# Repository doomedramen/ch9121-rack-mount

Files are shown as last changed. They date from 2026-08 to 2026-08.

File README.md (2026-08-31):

# CH9121 UART-to-Ethernet Rack Panel Carrier

> **Also in this repo:** [`pi5_ch9121_1u.scad`](pi5_ch9121_1u.scad) — a 1U
> 10-inch rack panel that holds one Raspberry Pi 5 and this carrier. See
> [the panel section](#1u-panel-raspberry-pi-5--carrier) at the bottom.

A rear-mounted 3D-printable **open tray** that holds a CH9121 UART-to-Ethernet
module behind a hand-cut opening in a Raspberry Pi rack fascia. The board's
2×8 pin header stays fully exposed so it can be wired to the Pi's GPIO with
dupont jumpers.

| File | Purpose |
|---|---|
| `ch9121_mount.scad` | Parametric OpenSCAD source. Every dimension is a named variable at the top. |
| `ch9121_carrier.stl` | Printable export. Manifold, genus 5 (RJ45 opening, 2 flange bores, 2 board bores). |
| `ch9121_coupon.stl` | **Print this first.** The front 14 mm of the part only — a few minutes on the bed. Checks that the board's screw holes and the magjack line up, and lets you test-press an insert before committing. |
| `ch9121_fascia_stencil.stl` | 2 mm flat plate for marking the fascia: flange outline, the 17.6 × 15.3 opening, and the two M2 holes. Hold it on the panel, mark or drill through, cut the opening to the line. Symmetric both ways so it can't go on backwards. |
| `renders/` | `iso.png` (into the tray), `fit.png` (module shown as reference geometry), `flange.png` (front elevation), `underside.png` (insert bores), `stencil.png`. |
| `render.sh` | Regenerates every STL and every PNG in `renders/` from the two sources. Run it after editing either. |

## Design

Open on top, screwed at both ends — no lid, no rails, no snap tab, no glue.

```
        flange (Z 0-4)          open tray (Z 4-48.2)
        +--------+
  RJ45  |  []    |======================\        <- side walls stop 7mm short
  hole  |        |   ribs carry the PCB  |          of the rear so nothing
        +--------+======================/          crowds the dupont housings
         ^      ^
         M2 inserts, screws enter from the front of the panel
```

- **X** = left / right
- **Y** = up / down — **Y = 0 is the top face of the tray floor**
- **Z** = front → back — Z = 0 is the outside face of the flange

Front to back: a 4 mm flange/front-stop slab with the RJ45 cutout and the two
M2 insert bosses, then a U-channel — floor plus two side walls — running back
48.2 mm. Two continuous ribs at the PCB's mounting-hole X positions run the
whole length of the tray and carry the M2 inserts the board screws down to.

Overall: **36 × 30 × 48.2 mm**.

### Two sets of brass heat-set inserts

**M2 throughout** — one insert size, one screw, one driver.

| Where | Bore | Depth | Screw enters from |
|---|---|---|---|
| Flange, 2 off at X ±14 | `flange_insert_d` 3.2 | 4.0 mm | the **front** of the rack panel |
| Tray ribs, 2 off at X ±10.16 | `pcb_insert_d` 3.2 | 4.0 mm | **above**, through the board's own holes (insert itself presses in from the tray *underside* — see below) |

The flange bores open at the front face and are backed by 2.5 mm bosses on the
rear face, giving 6.5 mm of stack for a 4 mm insert without thickening the
whole flange. Those bosses sit at Y 7.7–14.2, clear above the tray, so they
never foul the board.

The PCB bores open **downward, at the underside of the tray floor**, and the
insert is pressed in from there. It cannot go in from above: the bore mouth
sits 2.54 mm behind a flange that stands ~23 mm proud of the tray floor, and a
soldering iron's barrel fouls the flange long before the tip seats. The
underside is a flat open face with the flange protruding only 0.55 mm past it.
The screw then passes down through the board and a 2.4 mm clearance section to
reach the insert below — M2×6 gives 2.9 mm of engagement in the 4 mm insert
and still clears the tray bottom by 1.1 mm.

Those bores are cut in `pcb_screw_holes()` at **assembly level**, not inside
`pcb_rails()`. The tray floor is a separate solid, so subtracting them from the
ribs alone leaves the floor plugging the bottom of every bore — which is
exactly what happened, and is why the exported genus is worth checking (5:
RJ45 opening, two flange bores, two board through-holes).

Where the board is allowed to touch is driven by what hangs below it. The
magjack's heat-staked pegs and their solder joints span up to ~15.3 mm, so the
seating ribs start at X ±9.6, leaving a 19.2 mm clear channel — 1.95 mm of
margin each side. Only a short pad at each screw position (Z 4–9.3, forward
of the pegs) reaches inboard to ±7.8 to give the M2 bore a 0.76 mm collar.
Under the header the ribs are cut away to the floor entirely, so it makes no
difference exactly where the header pads sit; the board is supported for its
first 32 mm and cantilevers the last 11 mm, which 1 mm FR4 handles fine.

## The module

Measured off the board with calipers. It is an imperial design — 1″ wide,
0.1″ hole inset, 0.1″ header pitch:

| | |
|---|---|
| PCB | **25.4 × 43.18 × 1.0 mm** (1″ × 1.7″) — the 23 mm width repeated across listings is wrong |
| RJ45 magjack (HanRun HR911105A) | 12.7 mm (0.5″) tall above the board, overhangs the front edge by 5.08 mm (0.2″) |
| Mounting holes | Two, at the front corners, **2.54 mm (0.1″) diameter**, centres 2.54 mm (0.1″) in from every edge → X ±10.16, 2.54 back from the front |
| Under the board | 3 mm of solder tail to clear |
| 2×8 header | rear edge, 0.1″ pitch, pins stand 7.62 mm (0.3″) proud |

The board is pushed forward until its front edge butts the back face of the
flange slab at Z = 4.0 — that is its only hard stop, so it is where the board
actually sits. The magjack overhangs 5.08 mm against a 4.0 mm slab, so the
connector face ends up **1.08 mm proud** of the flange and noses into the
fascia cut-out. Screw positions are measured from that seated position, so
`pcb_front_z` must equal `front_t`; there is an assert on it.

## Print the coupon first

```bash
/Applications/OpenSCAD.app/Contents/MacOS/OpenSCAD --backend=manifold -o ch9121_coupon.stl -D 'part="coupon"' ch9121_mount.scad
```

It's the front 14 mm of the part — flange, both insert bosses, both flange
screw holes, the RJ45 opening. Sit the board against it and check the two
screw holes line up and the magjack drops into the opening. That's the whole
risk, and it costs a few minutes of filament instead of a two-hour print.

The RJ45 opening started deliberately loose and has been closed up over two
coupon prints. It now sits at **16.8 × 14.5** — 0.4 mm per side on width
(`rj45_clear_x`), 0.9 mm per side on height (`rj45_clear_y`) — and the whole
opening is lifted 1 mm by `rj45_y_trim`, because the connector sits that much
higher than `pcb_top_y + rj45_body_h/2` predicts.

If you ever change `rj45_body_h`, `standoff_h` or `pcb_t`, open both clearances
back out to ~1.5 and re-print the coupon before committing to a full part.

## Still to confirm

| Variable | Default | What to check |
|---|---|---|
| `pcb_insert_d` / `flange_insert_d` | 3.2 | Both are M2. 3.2 suits the common M2×4.0 insert with a 3.2 mm OD, but some M2 inserts want 3.5 — check yours before pressing. |
| `rib_inner_x` | 9.6 | Must clear the magjack's underside pegs (photos put them around ±6.5) and the header pins at ±8.89. |

Everything else is measured. If a number turns out wrong, it's one variable at
the top of the `.scad` — change it, re-run, and the asserts will tell you if
the change broke something else.

Three of those asserts currently pass by less than a print's worth of error,
so a clean render is weaker evidence than it looks — check them with calipers
on the coupon rather than trusting the model:

| Assert | Required | Actual | Slack |
|---|---|---|---|
| seating band wide enough to hold the board flat | 3.0 | 3.1 | 0.1 |
| ribs clear of the header pins | 9.39 | 9.6 | 0.21 |
| standoffs clear the RJ45's underside posts | 0.5 | 0.6 | 0.1 |

They are this tight because `rib_inner_x` is squeezed from both sides — the
header pins push it outboard, the seating band pulls it inboard — and it is
the one dimension in the table above that is still unverified. Confirm the
magjack and header spans on a real board before widening either bound.

## Printing

- PETG preferred; PLA or ABS/ASA fine.
- **Flange face down on the bed** (the default orientation in the file).
- **No supports needed.** Nothing in the model overhangs in −Z: the tray, the
  ribs and the gussets are all rooted in the flange slab at Z = 4 and grow
  straight up, and the bosses are rectangular rather than round for exactly
  that reason. The only overhangs are the tops of the two M2 bores, which are
  3.2 mm horizontal holes — they bridge fine, and a heat-set insert melts
  through any droop anyway.
- Walls 2.0 mm, floor 2.5 mm, flange 4.0 mm.

## Rebuilding

```bash
/Applications/OpenSCAD.app/Contents/MacOS/OpenSCAD --backend=manifold -o ch9121_carrier.stl ch9121_mount.scad
```

`part` selects what gets exported — `"carrier"` (default), `"coupon"` or
`"stencil"`:

```bash
OS=/Applications/OpenSCAD.app/Contents/MacOS/OpenSCAD
$OS --backend=manifold -o ch9121_carrier.stl        ch9121_mount.scad
$OS --backend=manifold -o ch9121_coupon.stl         -D 'part="coupon"'  ch9121_mount.scad
$OS --backend=manifold -o ch9121_fascia_stencil.stl -D 'part="stencil"' ch9121_mount.scad
```

`show_reference = true` adds translucent PCB / magjack / header stand-ins for a
visual fit check. Leave it `false` when exporting.

`./render.sh` regenerates every STL and every PNG in `renders/` in one go,
with the camera angles and colour schemes the committed images use. Run it
after any change to either source so the checked-in artefacts don't drift
from the code.

## Hardware

| | |
|---|---|
| Inserts | 4 × M2 heat-set, **4.0 mm long, 3.2 mm OD**. One size covers both bores. |
| Screws | 4 × **M2×6 button head**. Length is measured under the head, so it is 6 mm of penetration at both ends. |

Button head rather than countersunk on the board: the PCB's holes are
plain-drilled, so a conical head cannot seat — it bears on a 1.27 mm rim of
FR4 and wedges. Countersunk would be fine on the flange (flush panel) but then
you would have to countersink the fascia by hand, and button head costs only
~1.1 mm of head standing proud.

**Do not use M2×8 on the board** — 7 mm of penetration against 6.1 mm of
material punches through the tray floor. M2×8 is fine on the flange if your
fascia is thicker than ~3 mm; the relief bore runs right through, so the tip
just enters open air behind.

## Assembly order

1. Print `ch9121_coupon.stl`. Check the screw holes line up, the magjack drops
   into the opening, and an insert presses in cleanly.
2. Print `ch9121_carrier.stl` and `ch9121_fascia_stencil.stl`.
3. **Dry-fit the board before pressing any inserts.** They do not come out.
4. Press the two board inserts in from the **tray underside**, and the two
   flange inserts in from the **front face**. Seat each a hair below flush —
   proud stops the part sitting flat, and on the flange it holds the carrier
   off the panel. Scrape back any ridge of displaced plastic.
5. Hold the stencil on the fascia, mark through it, cut. That is a
   17.6 × 15.3 mm opening (`rack_hole_w` / `rack_hole_h`, the printed opening
   plus 0.4 mm per side) plus two M2 clearance holes at 28 mm spacing. It
   clears the 1.08 mm of magjack standing proud of the flange with 0.8 mm to
   spare all round.
6. Screw the carrier to the fascia, then the board into the tray.

---

## 1U panel: Raspberry Pi 5 + carrier

`pi5_ch9121_1u.scad` is a 254 × 44.0 mm 10-inch-rack 1U panel adapted from the
reference mounts in `pi_references/`. **The carrier is part of the print**: the
panel `include`s `ch9121_mount.scad` and unions `ch9121_carrier()` onto the
back of the fascia, flange face flush with the panel front. The carrier's two
flange screws and bosses are dropped (`include_flange_screws = false`) — there
is nothing to screw to when the flange grows out of the panel — and the fascia
carries the carrier's own test-fitted 16.8 × 14.5 opening rather than the
looser hand-cut stencil hole. All carrier dimensions stay in
`ch9121_mount.scad`; there is one source of truth.

| File | Purpose |
|---|---|
| `pi5_ch9121_1u.scad` | Parametric source. Pi 5 dimensions verified against the official mechanical drawing. |
| `pi5_ch9121_1u.stl` | The panel. Manifold, genus 8 (4 ear slots, Pi port opening, RJ45 tunnel, 2 carrier board bores). |
| `pi5_ch9121_1u_coupon.stl` | Front 14 mm slice — checks the Pi port opening and the CH9121 board alignment before a full print. |
| `renders/panel_*.png` | `iso`, `fit` (Pi / cooler / adapter / CH9121 ghosts), `front`. |

*A subtlety for anyone editing the source: the model is authored in a
mirrored frame (+X = the front viewer's **left**) and the final assembly
emits `mirror([1,0,0])` of everything — that mirror is what puts the Pi's
power/HDMI edge on the open-bay side. A Pi with ports facing front and
cooler up has its power edge on the viewer's left; there is no way to flip
it without pointing the ports backwards or the cooler down.*

**Layout, viewed from the front, left → right:**

1. **Open cable bay** (~110 mm) — the Pi's USB-C power and micro-HDMI → HDMI
   adapter exit sideways into this space. The adapter plus a mated full-size
   HDMI plug needs ~75 mm; there is ~110.
2. **Pi 5 bay** — board flat, Active Cooler up, USB/Ethernet through the
   fascia (flush: the ports overhang 3.0 mm against a 3 mm fascia, per the
   official drawing), SD card reachable from the rear. The board sits on two
   full-length rails rooted in the fascia, on four **M2.5** heat-set inserts
   (bore 3.5, pressed in from above), screwed with **M2.5×6** through the
   Pi's corner holes. The Active Cooler uses its own two dedicated holes, so
   the corners stay free. Those cooler holes sit 6 mm inboard of the rail
   lines at exactly the insert positions (official drawing: 6 mm from the
   GPIO-corner and USB-C-corner mounting holes), and the cooler's spring
   pins clip **through** the board and flare ~2.5 mm below it — which caps
   how far a rail may reach inboard at 2.75 mm (0.25 mm to spare at a 6 mm
   flare). The rails are **centred** on their hole lines at that reach, 5.5 mm
   wide, so each insert bore sits mid-rail with a 1.0 mm wall all round and
   the iron goes in straight. Asserts guard the clip clearance, the
   insert-bore wall, and the rails being centred.

   Each bore mouth is sunk by a 4.0 × 0.3 mm relief counterbore. These
   inserts press from *above* — unlike the carrier's, there is no reaching
   them from below — which puts the insert's own top face right at the
   board's seating plane, so one left standing proud would lift the Pi onto
   four rims and let it rock. The relief gives a proud insert somewhere to
   go. It leaves 0.75 mm of wall at the rail top and costs 0.3 mm of thread
   engagement (4.1 mm of an M2.5×6 still bites), both asserted.

   On the screws themselves: the Pi's holes are 2.7 mm, the close-fit
   clearance hole for M2.5, so an M2.5×6 passes with 0.1 mm a side. That is
   almost no positional slack and all four have to line up at once, so what
   will fight you on assembly is print shrinkage across the 58 × 49 pattern,
   not the screw diameter — start all four before tightening any.
3. **CH9121 station** — the carrier, printed in place, RJ45 centred at X +85.
   Its board inserts still press in from the tray underside, which stays open
   below. The Pi's GPIO edge faces it, so the dupont run to the header is
   short.

The board seats a full PCB thickness lower than the opening implies: the
opening's bottom edge lands 0.25 mm below the PCB **top** face, so the board
nose hides behind the fascia and butts it as a full-width hard stop — only
the ports pass through. The spare ~1.85 mm of opening height sits above the
ports and absorbs any error in the port-stack height. Cooler headroom: PCB
top sits at Y −7.5, cooler reaches ~+6.2 against a +22.25 panel edge. HDMI
adapter body reaches ~3 mm below the PCB underside; the tray floor is
5.9 mm below it.

**Rack geometry.** 10-inch racks are a de-facto convention, not a
standards-body format, but they reuse EIA-310's vertical geometry: a U is
1.75 in = **44.45 mm**, split 0.5 / 0.625 / 0.625 in, which is what puts the
two ear slots 1.25 in = 31.75 mm apart. The panel itself is **44.0 mm**, the
usual real-world 1U panel height — a panel has to sit *inside* its U, not
fill it exactly, or it binds on its neighbours. (It was 44.5 mm, i.e. taller
than the U; `assert(panel_h < rack_u)` now catches that.) Ear slot size and
the horizontal ±119 mm spacing come from the reference mounts in
`pi_references/`, not from a published spec — no citable standard for
10-inch ear holes seems to exist.

**Printing:** fascia face down, same as the carrier — everything grows
straight back, no supports. Rotate 45° on the bed if the 254 mm width does
not fit square; the orientation relative to the bed normal is what matters.

Both parts print with their front face on the bed, so that face's first
layer squashes outward and every opening through it comes out slightly
under size at the very front. Each such opening has a 0.3 × 0.3 mm 45°
lead-in on the bed face to absorb it. The relief only ever removes material,
so it cannot tighten the carrier's test-fitted 16.8 × 14.5 RJ45 opening.

Note what that orientation costs: the tray is a cantilever rooted at the
fascia, and the build axis runs along its length, so the Pi's weight is
carried across layer interfaces rather than in-plane. Static load is not
the worry — levering on a plugged-in cable is. Two stiffening ribs run
under the floor at its outer edges, deepening the section over the root
where the bending is. They are a long shallow taper (3 mm deep over 40 mm,
~5.7° off vertical), not 45° knee braces; the taper is what makes them
print with no support, since every layer going back is smaller than the one
below. Rib depth is capped by the 1U envelope, not by strength — they set
the tray's real low-water mark and are asserted against it, and at 3 mm they
sit exactly on the 1 mm clearance the assert allows.

The corner where the floor's top face meets the back of the fascia carries
a 2.5 mm fillet. That corner *is* the cantilever root, so it is where a
bending crack would start; a sharp internal corner there is a stress riser
for free. It grows in +Z like everything else, so it costs nothing to print
and never reaches the board seating plane 5.9 mm above it.

```bash
OS=/Applications/OpenSCAD.app/Contents/MacOS/OpenSCAD
$OS --backend=manifold -o pi5_ch9121_1u.stl        pi5_ch9121_1u.scad
$OS --backend=manifold -o pi5_ch9121_1u_coupon.stl -D 'part="coupon"' pi5_ch9121_1u.scad
```

Hardware for the whole panel: **4 × M2.5 heat-set inserts (3.5 mm bore —
VERIFY yours; press them until they sit at or below the rail top, the
0.3 mm relief is there to absorb the overshoot) + 4 × M2.5×6 screws** for
the Pi, and **2 × M2 inserts +
2 × M2×6** for the CH9121 board (pressed from the tray underside, exactly as
on the standalone carrier). The carrier's flange inserts and screws are not
used — the flange is printed into the panel.

There is also `ch9121_rj45_cutter.stl` — a plain 16.8 × 14.5 × 40 cuboid of
the test-fitted RJ45 opening, centred on the origin, for subtracting the same
opening from any other model (`part="cutter"` in `ch9121_mount.scad`).

## Sources

Where the numbers come from, so the next person can re-check them rather than
re-measure everything:

| What | Source |
|---|---|
| Pi 5 board, hole pattern, port overhang | [Official mechanical drawing](https://datasheets.raspberrypi.com/rpi5/raspberry-pi-5-mechanical-drawing.pdf) — 85 × 56 board, 2.7 mm corner holes on a 58 × 49 pattern, ports overhang 3.0 mm. Read 58 as the *hole spacing*, not the board width; it is easy to misread off the drawing. |
| Active Cooler height | [Official mechanical drawing](https://datasheets.raspberrypi.com/cooling/raspberry-pi-active-cooler-mechanical-drawing.pdf) — 13.7 mm above the PCB. The model budgets 16. |
| Rack geometry | 10-inch racks are a de-facto convention with no standards-body document, but reuse EIA-310's vertical geometry: 1.75 in U, ear slots 1.25 in apart. |

Two things are **not** in any official document, and the model is deliberately
pessimistic about both rather than pretending otherwise:

- **The Active Cooler's push-pin holes and the clip that flares under the
  board.** Neither Raspberry Pi drawing dimensions them. `fan_lug_d = 6.0`
  overstates the flare on purpose, because a bigger flare forces a *narrower*
  rail — that is the safe direction to be wrong. Scaling the cooler drawing
  suggests the real flare is nearer 3.6, so do not shrink this to justify a
  wider rail without measuring a real cooler. `fan_lug_below = 3.2` errs the
  other way for the same reason: a deeper clip needs *more* air under the
  board.
- **How far a micro-HDMI plug hangs below the PCB.** No Raspberry Pi or
  connector figure exists. Generic Type-D plug bodies run 2.8–3 mm, which is
  where `hdmi_below_pcb = 3.0` comes from. Measure your own adapter.

Heat-set insert bores are brand-dependent and every source says to test rather
than trust a number: M2 lands around 3.2–3.4 mm and M2.5 around 3.5–3.7 mm
across brands. The model uses the low end of each (3.2 and 3.5). Press a test
insert into the coupon before committing to a full print.

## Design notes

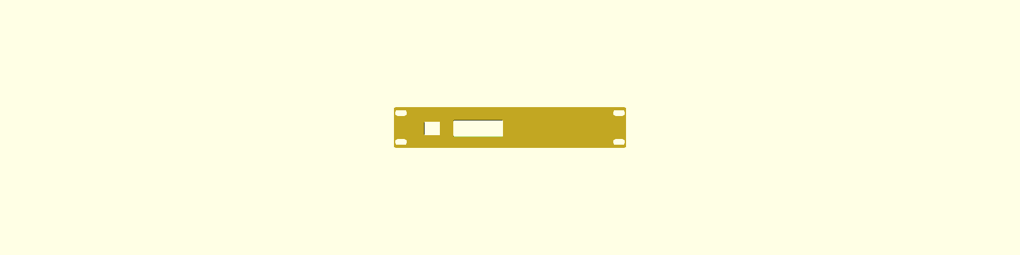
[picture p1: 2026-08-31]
renders/panel_front.png

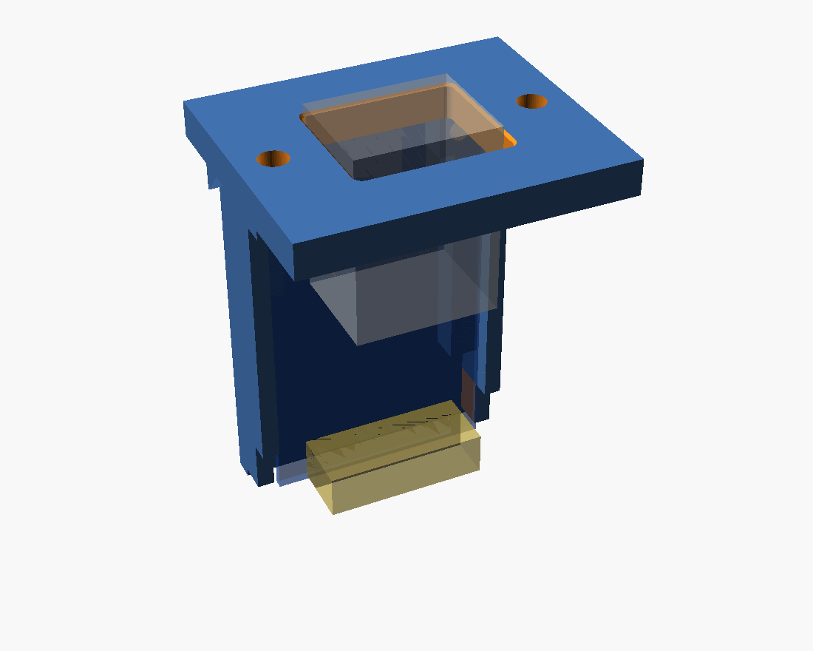
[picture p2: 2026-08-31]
renders/fit.png

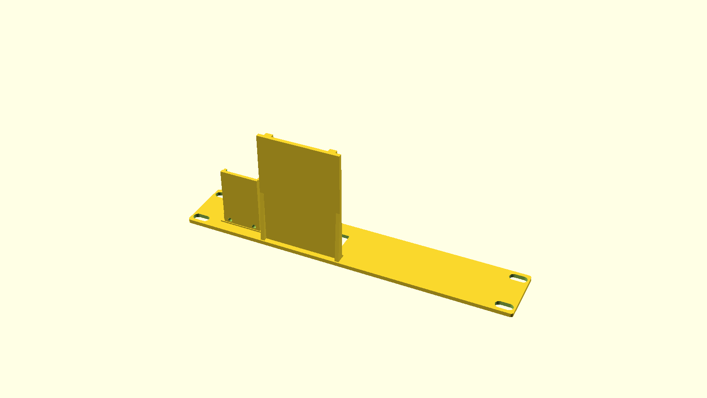
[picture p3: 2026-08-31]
renders/panel_iso.png

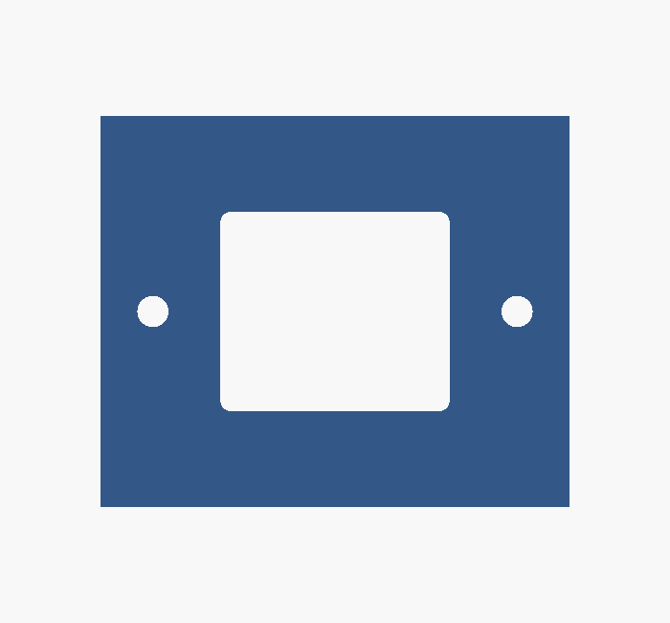
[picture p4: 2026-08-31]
renders/stencil.png

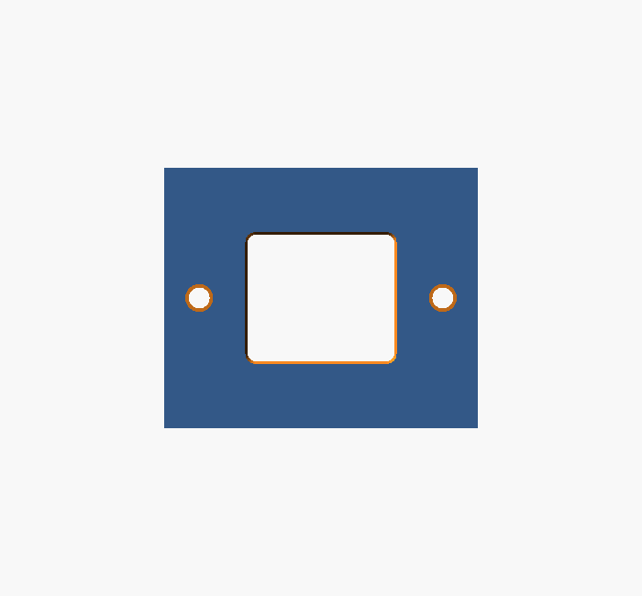
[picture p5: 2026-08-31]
renders/flange.png

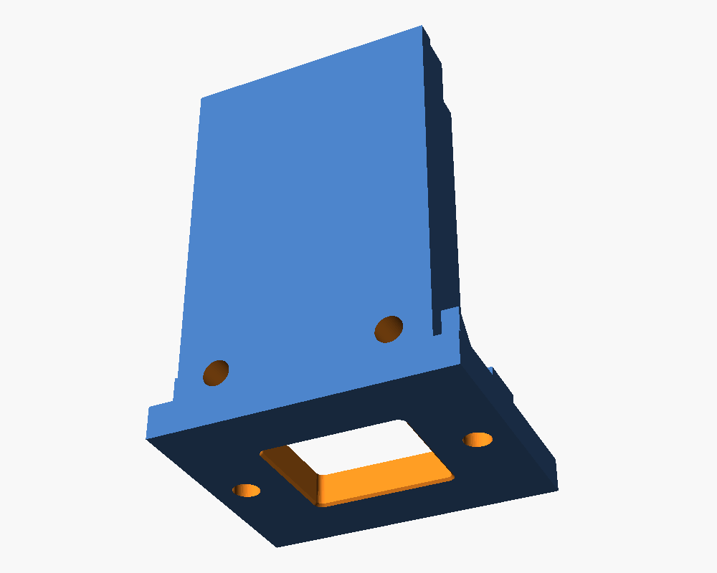
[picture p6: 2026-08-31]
renders/underside.png

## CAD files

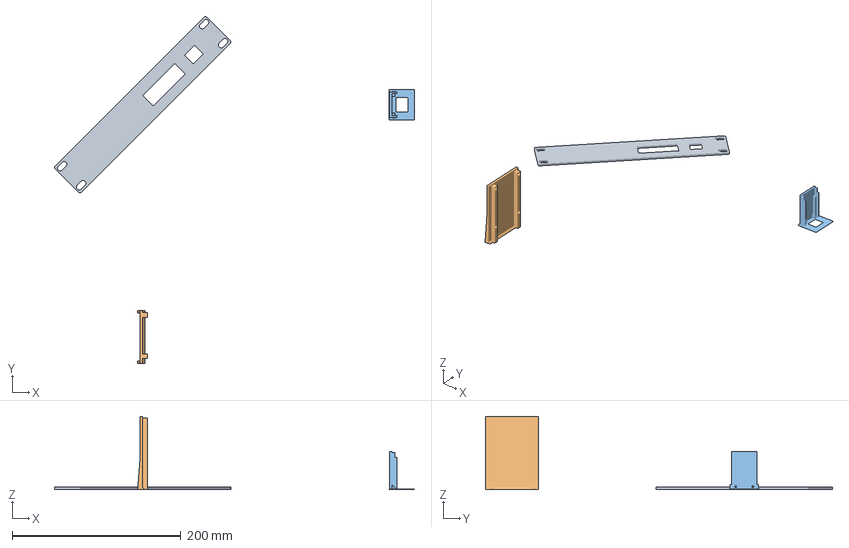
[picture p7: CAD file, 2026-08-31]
pi5_ch9121_1u.3mf
426.7 x 411.2 x 87.0 mm
pi5_ch9121_1u.stl_B
pi5_ch9121_1u.stl_A_A
pi5_ch9121_1u.stl_A_B

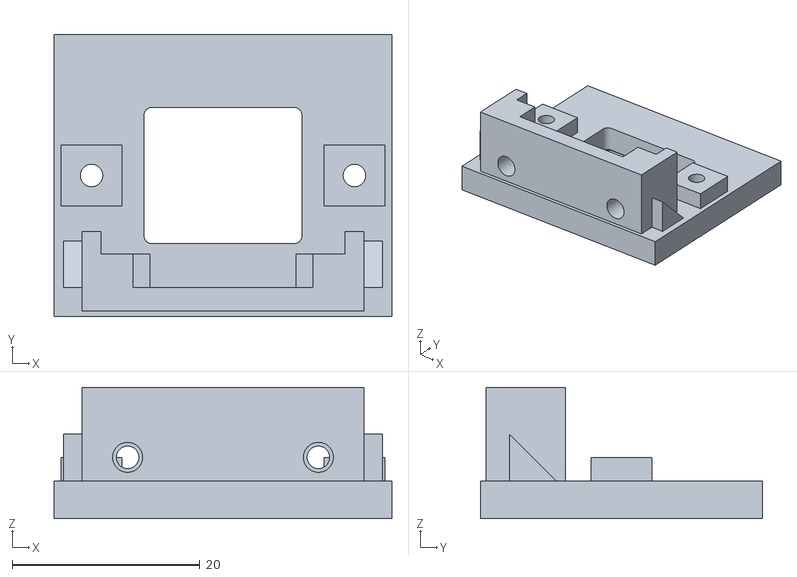
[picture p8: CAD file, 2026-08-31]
ch9121_coupon.stl
36.0 x 30.0 x 14.0

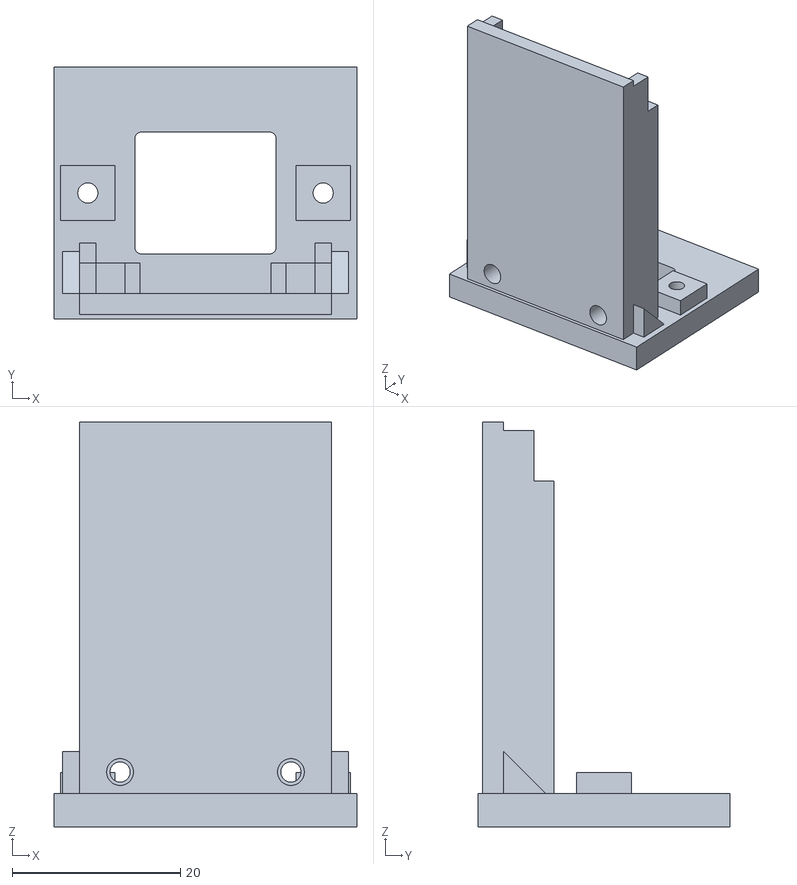
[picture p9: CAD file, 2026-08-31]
ch9121_carrier.stl
36.0 x 30.0 x 48.2

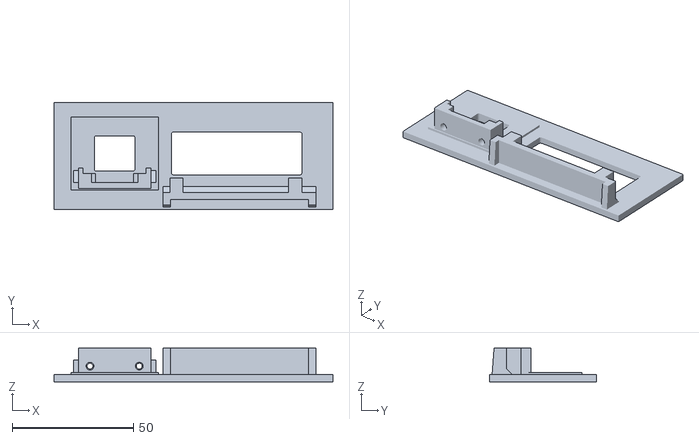
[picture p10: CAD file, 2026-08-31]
pi5_ch9121_1u_coupon.stl
115.0 x 44.0 x 14.0

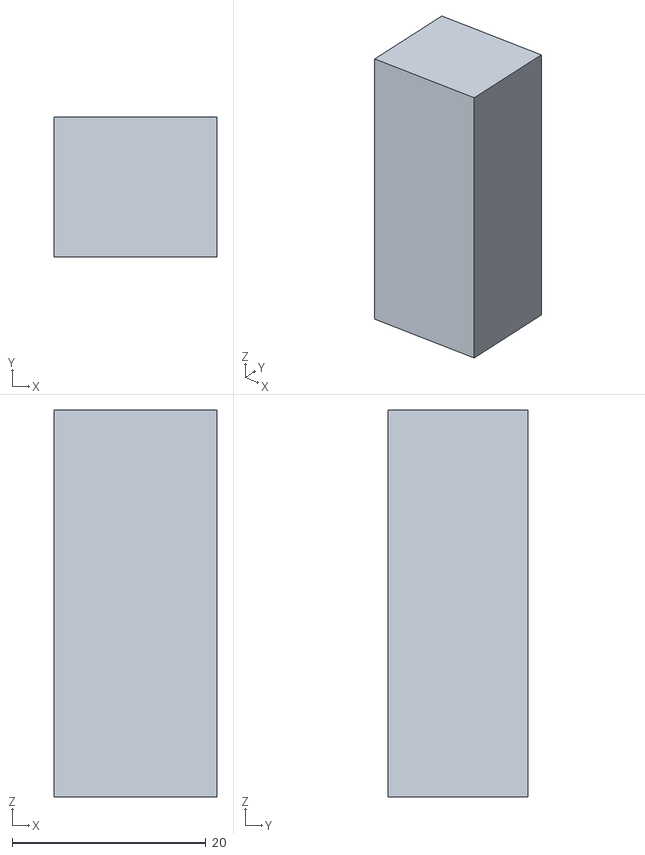
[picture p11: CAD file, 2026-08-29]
ch9121_rj45_cutter.stl
16.8 x 14.5 x 40.0

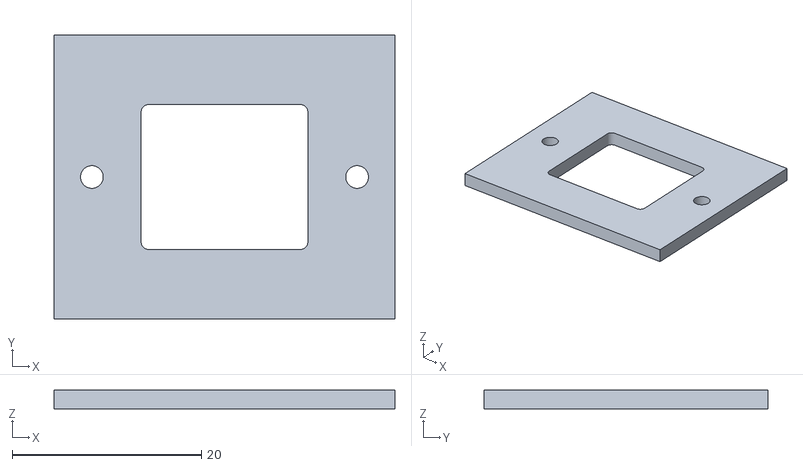
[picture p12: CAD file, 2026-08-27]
ch9121_fascia_stencil.stl
36.0 x 30.0 x 2.00

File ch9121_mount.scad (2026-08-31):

// ============================================================================
// CH9121 UART-to-Ethernet Rack Panel Carrier  --  OPEN TRAY REVISION
//
// Rear-mounted carrier for a Raspberry Pi rack fascia panel.
//
// Design intent (revised):
//   * OPEN TOP. The 2x8 pin header on the rear edge of the module is wired to
//     the Pi's GPIO with dupont jumpers, so there is no lid, no rails and no
//     snap tab - the board drops straight in from above.
//   * SCREWED, NOT GLUED. Brass heat-set inserts in two places:
//       - flange inserts  : carrier -> rack fascia (screws enter from the
//                           front of the panel)
//       - PCB bosses      : CH9121 board -> carrier floor (screws enter from
//                           above, through the board's own two holes)
//
// PRINT ORIENTATION: flange face flat on the bed at Z=0, carrier grows up in
// +Z. Nothing in the model overhangs in -Z, so no supports are needed.
//   X = left / right
//   Y = up / down        (Y=0 is the top surface of the tray floor)
//   Z = front -> back    (Z=0 is the exterior face of the flange)
//
// >>> Dimensions marked "VERIFY" are read off seller photos / a seller
// >>> dimension drawing, not a datasheet. Check with calipers before a
// >>> production print.
// ============================================================================

$fn = 48;

// Overlap for difference() cutters. Only ever used to push a cut face off a
// coincident plane so it does not z-fight; far below one layer height, so it
// never removes material that matters.
eps = 0.01;

// Elephant's foot relief. Both parts print with their front face flat on the
// bed, so that face's first layer squashes outward - which makes every
// opening through it come out UNDER size at the very front. A 45-degree
// lead-in over the first bed_relief_h of Z gives the squeeze-out somewhere to
// go. It only ever removes material, so it cannot tighten a fit that was
// dialled in on a test print.
bed_relief   = 0.3;   // how much wider the opening is at the bed face
bed_relief_h = 0.3;   // over how much Z it tapers back to nominal

// ---------------------------------------------------------------------------
// 1. THE MODULE  (measured off the board with calipers)
// It is an imperial design: 1.00in wide, 1.70in long, holes inset 0.10in,
// 0.1in header pitch. Retail listings widely repeat "43 x 23 x 14.5mm" - the
// 23 is simply wrong, and the caliper measurement is what is used here.
// ---------------------------------------------------------------------------
pcb_l = 43.18;   // PCB length, front (RJ45) edge to rear (header) edge
                  // measured, 1.7 inch (excludes the magjack overhang)
pcb_w = 25.4;    // PCB width - measured, exactly 1 inch
pcb_t = 1.0;     // PCB thickness - measured

// The RJ45 magjack hangs off the front edge of the PCB. This is the single
// most important number in the file: the front slab MUST be thinner than it,
// or the connector cannot reach the outside of the panel.
rj45_overhang = 5.08;   // measured, 0.2 inch

rj45_body_w      = 16.0;   // magjack shell width
rj45_body_h      = 12.7;   // magjack shell height above the PCB top face
                            // measured, 0.5 inch
underside_clear  = 3.0;    // measured - the header's solder tails are the
                            // long thing under there, not the magjack

// The module's two mounting holes, both near the front (RJ45) corners.
// Hole centres measured 0.1 inch in from every edge - both sides and the
// front. Corner holes on a 0.1 inch grid, consistent with the rest of the
// board being an imperial design.
pcb_hole_dx   = pcb_w/2 - 2.54;   // = 10.16
pcb_hole_dz   = 2.54;             // back from the PCB front edge
// Holes measure 2.54mm (0.1 inch) across. That is below M2.5 clearance
// (2.7-2.9), so the board takes M2 screws. M2 is also the safe way to be
// wrong here: an M2 screw still passes a 3mm hole, whereas an M2.5 screw
// will not pass a 2.54mm one.
pcb_hole_d        = 2.54;  // measured, for reference
pcb_insert_d      = 3.2;   // M2 heat-set insert bore                  VERIFY
pcb_insert_depth  = 4.0;   // insert length + a little
pcb_screw_d       = 2.4;   // M2 clearance, insert up to the seating face
board_screw_len   = 6.0;   // M2x6 button head, length measured under the head

// The board inserts are installed from the UNDERSIDE of the tray floor, not
// from above. Above, the bore mouth sits 2.54mm behind a flange that stands
// ~23mm proud of the tray floor - a soldering iron cannot get a tip down
// there without its barrel melting the flange. The underside is a flat, open
// face with the flange protruding only 0.55mm past it, so the iron goes
// straight in. The screw then passes down through the board and a clearance
// hole to reach the insert below.

// Inner edge of the two support ribs. The board rests on these, so they must
// stay clear of everything hanging off the UNDERSIDE of the magjack - its two
// heat-staked pegs (roughly +/-6.5 on the photos) and the RJ45 solder tails.
// What hangs below the board decides where it can rest.
//   - under the magjack: solder tails plus two heat-staked pegs / shield tabs,
//     measured 0.5-0.6 inch across (call it 15.3mm worst case)
//   - under the header: 8 positions at 0.1 inch pitch, so pins at +/-8.89
// The ribs the board seats on therefore start at 9.6, outboard of both, and
// run the full length of the tray. Only a short pad at each screw position
// reaches inboard to 7.8 to carry the insert bore - and that pad sits at
// z 4..10.6, forward of where the magjack's pegs are.
magjack_underside_span = 15.3;   // widest thing under the connector  VERIFY
header_half_span       = 8.89;   // 8 positions at 0.1 inch pitch
header_pin_h           = 7.62;   // 0.3 inch above the board (reference only)

rib_inner_x  = 9.6;   // seating band starts here
boss_inner_x = 7.8;   // local insert pad reaches this far in
boss_pad_z   = 1.2;   // pad overrun behind the bore

// Over the rear of the tray the ribs are cut away to the floor completely.
// The header's solder tails are 3mm long and its pads run close to the board
// edge, so rather than depend on exactly where they sit, nothing is left for
// them to land on. The board is screwed at the front and supported for the
// first 32mm; the last 11mm cantilevers, which 1mm FR4 handles fine when you
// push a dupont connector on.
rear_rib_relief = 11.0;

// ---------------------------------------------------------------------------
// 2. RACK FASCIA HAND-CUT OPENING (reference only, you cut this by hand)
// ---------------------------------------------------------------------------
// NOTE: rack_hole_w / rack_hole_h are defined in section 3, below the printed
// opening they derive from. OpenSCAD does not resolve forward references in
// top-level expressions, so the order matters.

// Marking stencil: a flat plate with the same outline as the flange, the
// fascia opening, and the two screw holes. Hold it on the panel, mark or
// drill through it, cut the opening to the line.
stencil_t       = 2.0;
stencil_pilot_d = 2.4;   // M2 clearance, so an M2 drill can guide through it

// ---------------------------------------------------------------------------
// 3. CARRIER RJ45 OPENING (printed, tighter than the hand-cut hole)
// ---------------------------------------------------------------------------
// Set from two coupon prints. Width at 0.4 per side fitted; height needed
// another 0.5 per side, and the whole opening needed to come up 1mm. If you
// ever change rj45_body_h / standoff_h / pcb_t, open these back out to ~1.5
// and re-print the coupon before committing to a full part.
rj45_clear_x   = 0.4;    // per side
rj45_clear_y   = 0.9;    // per side
carrier_rj45_w = rj45_body_w + 2*rj45_clear_x;   // = 16.8
carrier_rj45_h = rj45_body_h + 2*rj45_clear_y;   // = 14.5

// The hand-cut fascia opening, derived from the printed one rather than from
// the connector, because the printed one is what has actually been test
// fitted. Cut by hand, so it gets a little more slack again.
rack_hole_clear = 0.4;   // per side, on top of the printed opening
rack_hole_w = carrier_rj45_w + 2*rack_hole_clear;   // = 17.6
rack_hole_h = carrier_rj45_h + 2*rack_hole_clear;   // = 15.3
carrier_rj45_r = 0.8;
rj45_y_trim    = 1.0;   // measured off a coupon print: the connector sits 1mm
                         // higher than pcb_top_y + rj45_body_h/2 predicts
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

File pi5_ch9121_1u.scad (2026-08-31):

// ============================================================================
// 1U 10-INCH RACK PANEL  --  ONE RASPBERRY PI 5  +  CH9121 CARRIER, ONE PIECE
//
// SOURCES for the numbers in section 2. Anything not traceable to one of
// these is measured off the reference OBJ and tagged VERIFY at its
// definition:
//   Pi 5 board + ports:
//     https://datasheets.raspberrypi.com/rpi5/raspberry-pi-5-mechanical-drawing.pdf
//     85 x 56 board, 2.7mm corner holes on a 58 x 49 pattern, 3.0mm port
//     overhang. (Beware: 58 is the HOLE SPACING, not the board width.)
//   Active Cooler:
//     https://datasheets.raspberrypi.com/cooling/raspberry-pi-active-cooler-mechanical-drawing.pdf
//     13.7mm tall over the PCB. It does NOT dimension the push-pin holes or
//     the under-board clip - see the fan_lug notes below.
//   Rack: 10-inch racks are a de-facto format, but reuse EIA-310's vertical
//     geometry - 1.75in U, ear slots 1.25in apart.
//
// Adapted from "RPi 2B/3B/4B/5B 10-inch Rack Mount V1_2" (pi_references/):
// same 254 x 3 fascia, same rack-ear slots, same print concept -
// fascia face down on the bed, everything grows straight back in +Z, nothing
// overhangs in -Z, no supports. Print rotated 45 degrees on the bed if the
// plate does not fit square - the orientation relative to the bed NORMAL is
// what matters, not the rotation about it.
//
// The CH9121 carrier is PART OF THIS PRINT: ch9121_mount.scad is included
// below and its ch9121_carrier() is unioned onto the back of the fascia,
// flange face flush with the panel front. Its two flange screws and bosses
// are dropped (include_flange_screws = false) - nothing to screw to when the
// flange grows out of the panel - and the fascia carries the carrier's own
// test-fitted 16.8 x 14.5 opening, not the looser hand-cut stencil hole.
// The carrier's two PCB inserts still press in from the tray underside,
// which stays open below.
//
// Layout of the EMITTED (mirrored) part, viewed from the FRONT of the
// rack, left to right:
//   1. open cable bay   - the Pi's USB-C power and the micro-HDMI -> HDMI
//                         adapter exit sideways (viewer's left) into ~110mm
//                         of open space
//   2. Pi 5 bay         - board flat, cooler up, USB/Ethernet through the
//                         fascia, SD card reachable from the rear
//   3. ch9121 station   - the carrier, printed in place. The Pi's GPIO edge
//                         faces it, so the dupont run is short.
//
// Axes (same convention as ch9121_mount.scad):
//   X = left / right, 0 at panel centre
//   Y = up / down,    0 at panel centre
//   Z = front -> back, 0 at the exterior face of the fascia
//
// HANDEDNESS - READ BEFORE TRUSTING ANY LEFT/RIGHT BELOW. For a viewer
// standing at the FRONT of the rack (looking along +Z, up +Y), viewer-right
// is -X. This file is AUTHORED in the mirror frame (+X = viewer-LEFT,
// where a physical Pi's layout constants read naturally), and the final
// assembly emits mirror([1,0,0]) of everything, producing the physical
// part. A physical Pi 5 with ports facing front and cooler up has its
// power/HDMI edge on the viewer's LEFT and GPIO on the viewer's RIGHT -
// the mirrored output honours that; the raw authored model does not.
//
// >>> Dimensions marked "VERIFY" are read off the reference STL / OBJ models,
// >>> not a datasheet. Check before a production print.
// ============================================================================

// All carrier dimensions and modules come from the carrier's own file - one
// source of truth. The three assignments after it suppress its standalone
// render and its flange screw hardware (main-file assignments override
// included ones in OpenSCAD).
include <ch9121_mount.scad>
ch9121_standalone     = false;
include_flange_screws = false;

// $fn comes from the included carrier file - one source of truth for both
// parts. Asserted below so a change there can't silently coarsen this panel.

// ---------------------------------------------------------------------------
// 1. PANEL / RACK  (measured off the reference 10-inch rack mount STL)
// ---------------------------------------------------------------------------
// 10-inch racks are a de-facto convention rather than a standards-body
// format, but they reuse EIA-310's vertical geometry: the U pitch is
// 1.75in = 44.45mm, split 0.5in / 0.625in / 0.625in, which is what puts the
// two ear slots 1.25in = 31.75mm apart (ear_slot_cy below).
rack_u    = 44.45;   // one rack unit, EIA-310
panel_w   = 254.0;   // 10-inch rack panel width
// A panel has to be UNDER the U pitch, not equal to it, or it binds against
// its neighbours. 44.0 is the usual real-world 1U panel height and leaves
// ~0.2mm top and bottom. (This was 44.5 - taller than the U it sits in.)
panel_h   = 44.0;
fascia_t  = 3.0;
panel_r   = 2.0;     // outer corner radius

ear_slot_cx = 119.0;  // slot centres, +/-X            (reference: 119.06)
ear_slot_cy = 15.875; // slot centres, +/-Y: EIA-310 puts them 1.25in apart
ear_slot_w  = 13.0;   // slot length (X)
ear_slot_h  = 6.5;    // slot width  (Y), ends fully rounded

// ---------------------------------------------------------------------------
// 2. RASPBERRY PI 5  (measured off the reference OBJ; holes cross-checked
//    against the official mechanical drawing)
// ---------------------------------------------------------------------------
pi_l = 85.0;    // board length, port edge to SD edge
pi_w = 56.0;    // board width
pi_t = 1.6;     // PCB thickness

// USB/Ethernet stack on the front edge: bodies overhang the PCB edge by
// 3.0mm (official mechanical drawing) - flush with the 3mm fascia - and rise
// 15.5mm above the PCB top face (measured, OBJ).                      VERIFY
pi_port_overhang = 3.0;
pi_port_h        = 15.5;
// The port bodies span 2.4..53.0 across the board, measured from the
// power/HDMI edge (OBJ).                                              VERIFY
pi_port_x0 = 2.4;
pi_port_x1 = 53.0;

// Mounting holes: 2.7mm, 3.5mm in from the edges, 58 x 49 pattern.
// Measured from the SD (rear) edge and the power/HDMI edge.
pi_hole_from_rear  = [3.5, 61.5];   // along the board length
pi_hole_from_pwr   = [3.5, 52.5];   // across the board width
pi_hole_d          = 2.7;           // the board's own holes, for reference

// micro-HDMI -> HDMI adapter: its body hangs below the PCB once plugged in,
// and the tray floor has to stay clear of it
hdmi_below_pcb  = 3.0;   //                                            VERIFY

// M2.5 hardware for the Pi. 2.7 is the close-fit clearance hole for M2.5 -
// too big for an M2 to locate in, exactly right for this. Note how little
// slack that is: 0.1mm a side, and all four have to line up at once, so
// print shrinkage across the 58 x 49 pattern is what will fight you on
// assembly, not the screw diameter. Start all four before tightening any.
pi_screw_d      = 2.5;   // M2.5 major diameter, for the clearance assert
pi_insert_d     = 3.5;   // M2.5 heat-set insert bore                  VERIFY
pi_insert_depth = 5.0;   // total bore depth from the rail top
pi_screw_len    = 6.0;   // M2.5x6, length under the head

// Relief counterbore at the mouth of each insert bore. The inserts press in
// from ABOVE (the floor is solid underneath, so there is no reaching them
// from below like the carrier's are), which puts the insert's own top face
// at the board's seating plane. Left flush, an insert that ends up even
// slightly proud lifts the Pi onto four rims and it rocks. Sinking the bore
// mouth by this much gives a proud insert somewhere to go.
// 4.0 is about the OD of a common M2.5 insert, which is the size that has to
// fit. If yours are fatter, this has to grow with them - and the rail cannot
// give much, so check the wall assert below rather than just widening it.
pi_insert_relief_d = 4.0;   // wider than the insert, to clear a flared knurl
pi_insert_relief_h = 0.3;   // deeper than an insert is likely to sit proud

// Official Active Cooler: 13.7mm above the PCB top face (official mechanical
// drawing; 16 kept as the clearance budget), fixed by its own two dedicated
// spring-pin holes - the four corner holes stay free.
cooler_h = 16.0;
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

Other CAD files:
pi5_ch9121_1u.stl

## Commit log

2026-08-27 Fix board insert installation and bore subtraction
    Two related fixes to how the board's heat-set inserts are made and fitted.
    Install the board inserts from the tray underside, not from above. The bore
    mouth sits 2.54mm behind a flange standing ~23mm proud of the tray floor, so
    a soldering iron's barrel fouls the flange long before the tip can seat. The
    underside is a flat open face with the flange protruding only 0.55mm past it.
    The screw now passes down through the board and a 2.4mm clearance section to
    reach the insert below: M2x6 gives 2.9mm of engagement in a 4mm insert and
    still clears the tray bottom by 1.1mm.
    Cut the board bores at assembly level in pcb_screw_holes() rather than in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
    [ch9121_carrier.stl, ch9121_coupon.stl, ch9121_mount.scad]
2026-08-31 better rails
    [pi5_ch9121_1u.scad, pi5_ch9121_1u.stl, pi5_ch9121_1u_coupon.stl]
2026-08-31 fit the panel inside a real 1U, add bed relief and a root fillet
    Panel was 44.5mm tall against a 44.45mm rack unit, so it would bind on its
    neighbours. Now 44.0 - the usual real-world 1U panel height - with rack_u
    named and asserted against. Ear slots moved to the exact EIA-310 1.25in
    spacing.
    Both parts print front-face-down, so that face's first layer squashes
    outward and every opening through it comes out under size. Added a shared
    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
    [ch9121_carrier.stl, ch9121_coupon.stl, ch9121_mount.scad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]
